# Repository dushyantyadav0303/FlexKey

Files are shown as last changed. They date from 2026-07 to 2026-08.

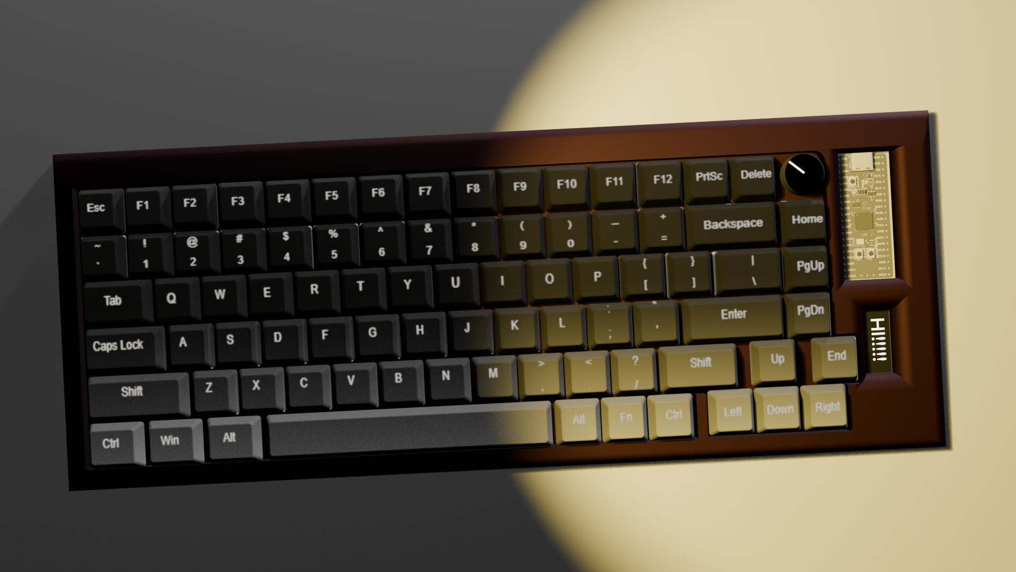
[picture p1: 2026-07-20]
Render/Untitled1.png

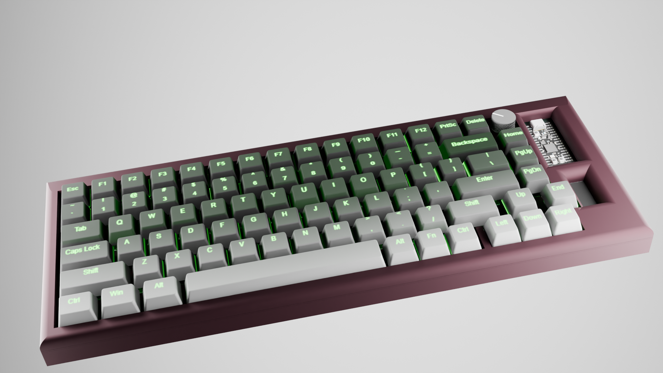
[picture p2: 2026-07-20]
Render/Untitled2.png

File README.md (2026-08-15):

<h1 align="center">
<br> banner
</h1>
<div align="center">  
  

</div>

<h4 align="center">
FlexKey: it is a Fully Customizable OpenSource 75% Mechanical Keyboard with Ai Powered customizable dashboard with allow user to Type a modify the there Keyboard.
</h4>

<div align="center">
  




</div>

<p align="center">
  <a href="#about-the-project">About</a> •
  <a href="#repository-structure">Structure</a> •
  <a href="#schematic">Schematic</a> •
  <a href="#pcb">PCB</a> •
  <a href="#cad">CAD</a> •
  <a href="#Render">Render</a> •
  <a href="#bill-of-materials">BOM</a> •
  <a href="#license">License</a> •
  <a href="#credits">Credits</a>
</p>  

<p
  align="center">
  
</p>

</p>

<br>
<br>
<p align=center>

demo

</p>

> [!IMPORTANT]
> # PLEASE Check [How-to-Build](https://github.com/dushyantyadav0303/FlexKey/blob/main/How-to-Build.md) 
> ### It contain Beginner Friendly Step by Step Assembly Instruction Docs.

### About the Project

**FlexKey:** It is a Fully Customizable OpenSource 75% Mechanical Keyboard with an Ai Powered customizable dashboard with allow user to Type a modify the there Keyboard.

### Features

- **Rpi2040 MCU**
- **Type-C/Micro-USB**
- **KMK Based Firmware**
- **75% keyboard with 84 Keys + Encoder**
- **Modify with Ai Dashboard**
- **Customizable RGB Matrix**

## Repository Structure

- `src/Kicad/` - Kicad PCB sources
- `src/CAD/` -  editable .STEP file 
- `src/CAD/Fusion 360/` - Fusion 360 CAD sources
- `src/Blender/` - Blender Render sources 
- `production/PCB/` - PCB fabrication files (Gerbers, BOM, positions)
- `production/CAD/` - 3D-printable files (.3mf/.stl)
- `GETTING_STARTED/` - Setup guides
- `Journal/` - DevLogs With Timestamp
- `Firmware/` - Base Firmare

## Schematic


Source : `src/Cad/.Sch`


## PCB 
Source : `src/Kicad/.Pcb`
<div align="center">

| Front PCB | Back PCB |
|---|---|
|  |  |
|  |  |

</div>

### Fabrication Production files are available in:
- source: `production/PCB/`

## CAD


- source: `src/Fusion 360/`
<div align="center">
<table>
<tr>
<td valign="bottom">
</td>
<td valign="bottom">
  </td>
<td valign="bottom">
</table>
</div>

> [!TIP]
> Wait for bed Plate to be cool down before Taking out prints. <br/>
> To prevent from warping and print bending issue.

### 3D-printable Production files are available in:
- source: `production/PCB/`

## Render 


<div align="center">
<table>
  
https://github.com/user-attachments/assets/db8a1d57-0f98-42ea-bc92-7f4cc1325804

</table>
</div>

## Bill of Materials

Source: `BOM/BOM.csv`

| Part name | Quantity | Designator | Footprint | Price (In INR) | Link to buy |
| --- | --- | --- | --- | --- | --- |
| RaspberryPi_Pico | 1 | A1 | RaspberryPi_Pico | 384 | [Buy](https://robu.in/product/raspberry-pi-pico) |
| 1N4148 | 84 | D1-D84 | D_SOD-123 | 1.54 | [Buy](https://robu.in/product/1n4148-1w-zener-diode-pack-of-50) |
| sk6812 mini-e | 83 | DL1-DL83 | SK6812MINI-E | 8.5 | [Buy](https://www.lcsc.com/product-detail/Light-Emitting-Diodes-LED_OPSCO-Optoelectronics-SK6812MINI-E_C5149201.html) |
| RotaryEncoder | 1 | EN1 | RotaryEncoder_EC11E-Switch_Vertical | 42 | [Buy](https://www.flyrobo.in/ec11-rotary-encoder-half-shaft-handle-potentiometer-15mm) |
| oled Disply | 1 | J1 | OLED_0.91_128x32 | 212 | [Buy](https://robu.in/product/blue-oled-display-module/) |
| Key Switches | 84 | SW1-SW84 | MX100H | 7.3 | [Buy](https://www.thecosmicbyte.com/product-category/keyboard-mechanical-switches/) |
| Keycaps | 2 | SW1-SW84 | MX200H | 999 | [Buy](https://amzn.in/d/0iVP38it) |
| Kailh Hot-Swap Sockets | 84 | SW1-SW84 | Kailh Hot-Swap Sockets (CPG151101S11) | 11.6 | [Buy](https://www.amazon.in/HEAVENGLOW-Socket-Connector-Keyboard-Switches/dp/B0H74X3QF5) |
| Stabilizers | 8 |  |  | 32 | [Buy](https://neomacro.in/products/cherry-pcb-mount-stabilizers-clip-in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) |
| Full Case | 1 |  | inc. bottom, Top & plate |  | 3D PRINTED |
| PCB  | 1 |  |  | 2,339 | [Buy](https://jlcpcb.com) |
| M3 heat Insert | 4 |  |  | 3.6 | [Buy](https://robu.in/product/m3-x-6-mm-brass-heat-set-knurl-threaded-round-insert-nut-25-pcs/) |
| M3 Screw H-20mm | 4 |  |  | 2.6 | [Buy](https://onlyscrews.in/products/m3-x-20mm-hex-allen-socket-head-high-tensile12-9-black-anodized-screw) |

> [!NOTE]
> Price As of August 15, 2026 
> & It not Include the Shipping fee <br/>

## License

Licensed under MIT - you can use this commercially, modify, distribute and  Flex key more 
with proper attribution. See [LICENSE](LICENSE) file.

## Contributing

Contributions, improvements, and remixes are welcome! Please read the [CONTRIBUTING.md](CONTRIBUTING.md) guide to get started.

## Credits
<div align="center">
  



 
</div>

This project was created during a [Hack Club](https://hackclub.com) event [Macondo](https://macondo.hackclub.com).
- **[Kicad](https://Kicad.org)** - PCB design and schematic capture
- **[Fusion 360](https://www.autodesk.com/products/fusion-360)** - Cad Designing
- **[Blender](https://www.blender.org)** - Render
- **[KMK firmware](https://github.com/KMKfw/kmk_firmware)**
- **[@NotARoomba](https://github.com/notaroomba) & [@Gabouin](https://github.com/Gabouin)** - Readme template

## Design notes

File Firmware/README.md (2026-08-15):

# Upload the Base Firmware in Keyboard

## Install CircuitPython in Flexkey

- Connect flexkey with your computer. press and hold boot button for 5 second
- A drive named `RPI-RP2` will appear on your computer.
- Download the CircuitPython for Raspberry Pi Pico from [circuitpython.org](https://circuitpython.org/board/raspberry_pi_pico/).
- drag and drop that file in drive `RPI-RP2`.
- Verify it: Check that the drive name become `CircuitPython` from `RPI-RP2`.

## Add kmk_firmware library
- Download the kmk_firmware library from [Repo](https://github.com/KMKfw/kmk_firmware/tree/main/kmk)
- Drag and Drop kmk folder in drive `CircuitPython/lib`

## Add firmware
- open [Firmware directory](https://github.com/dushyantyadav0303/FlexKey/tree/main/Firmware)
- copy all 3 file (code.py, boot.py, config.py)
- Paste in root of drive `CircuitPython`
- And here you go, Your firmware is successfully flashed and you can use the Flexkey

###  PLEASE Check [How-to-Build](https://github.com/dushyantyadav0303/FlexKey/blob/main/How-to-Build.md) for Detailed guide

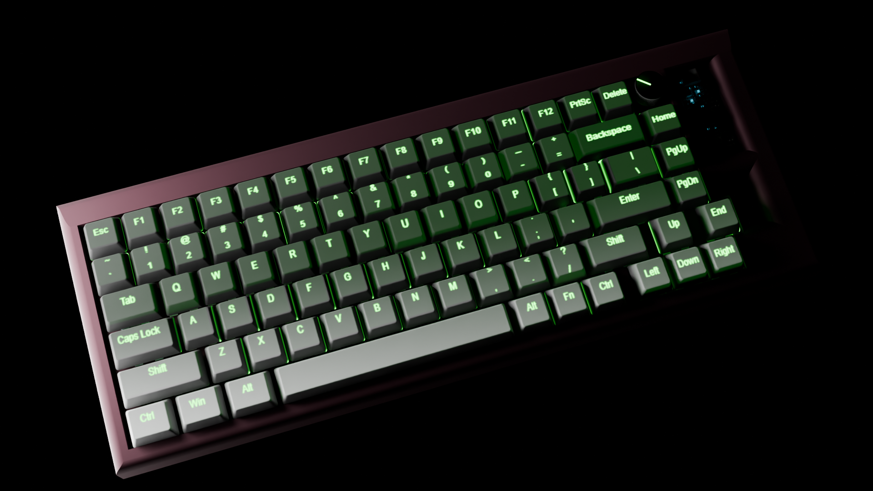
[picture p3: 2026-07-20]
Render/Untitled3.png

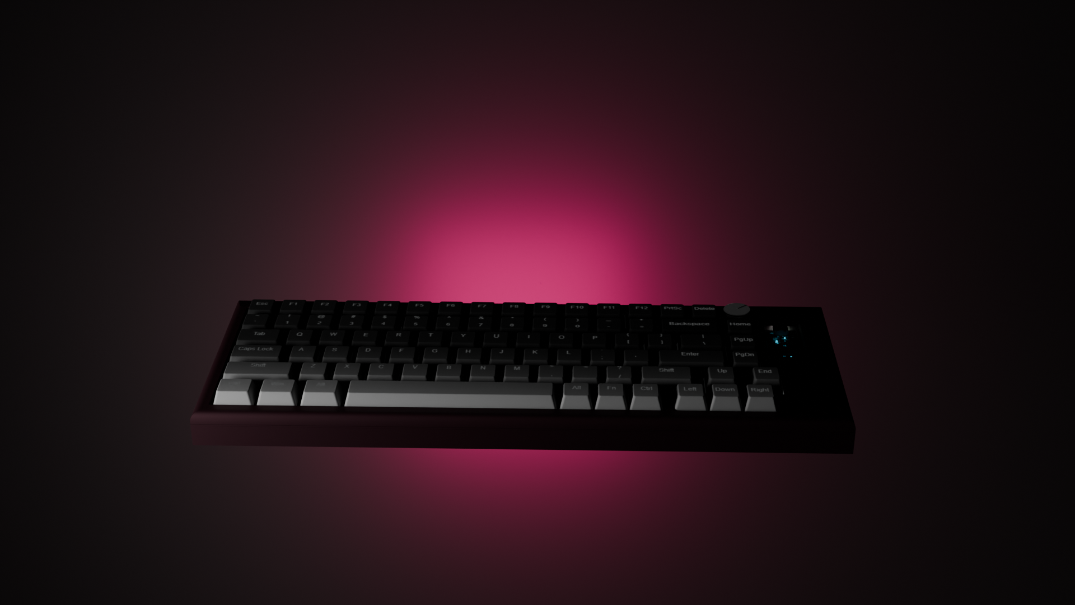
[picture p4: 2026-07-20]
Render/Untitled4.png

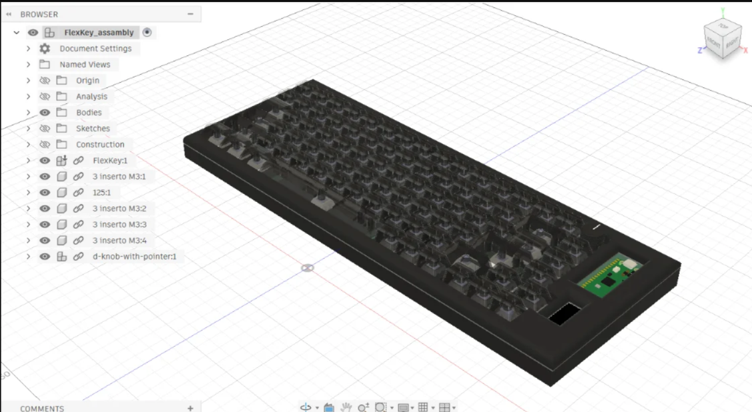
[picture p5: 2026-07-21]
src/CAD/Image.png

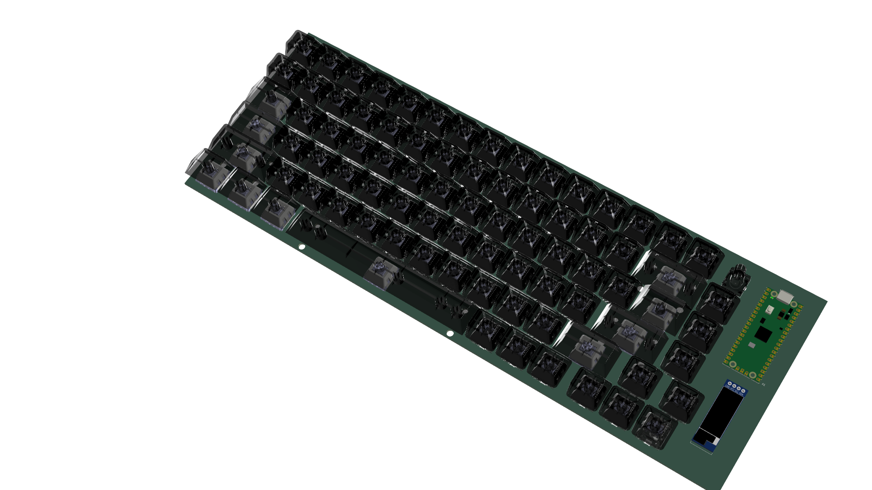
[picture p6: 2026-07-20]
src/Kicad/FlexKey.png

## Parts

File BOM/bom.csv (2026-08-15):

Part name | Quantity | Designator | Footprint | Price (In INR) | Link to buy
RaspberryPi_Pico | 1 | A1 | RaspberryPi_Pico | 384 | https://robu.in/product/raspberry-pi-pico
1N4148 | 84 | D1-D84 | D_SOD-123 | 1.54 | https://robu.in/product/1n4148-1w-zener-diode-pack-of-50
sk6812 mini-e | 83 | DL1-DL83 | SK6812MINI-E | 8.5 | https://www.lcsc.com/product-detail/Light-Emitting-Diodes-LED_OPSCO-Optoelectronics-SK6812MINI-E_C5149201.html
RotaryEncoder | 1 | EN1 | RotaryEncoder_EC11E-Switch_Vertical | 42 | https://www.flyrobo.in/ec11-rotary-encoder-half-shaft-handle-potentiometer-15mm
oled Disply | 1 | J1 | OLED_0.91_128x32 | 212 | https://robu.in/product/blue-oled-display-module/
Key Switches | 84 | SW1-SW84 | MX100H | 7.3 | https://www.thecosmicbyte.com/product-category/keyboard-mechanical-switches/
Keycaps | 2 | SW1-SW84 | MX200H | 999 | https://amzn.in/d/0iVP38it
Kailh Hot-Swap Sockets | 84 | SW1-SW84 | Kailh Hot-Swap Sockets (CPG151101S11) | 11.6 | https://www.amazon.in/HEAVENGLOW-Socket-Connector-Keyboard-Switches/dp/B0H74X3QF5
Stabilizers | 8 |  |  | 32 | https://neomacro.in/products/cherry-pcb-mount-stabilizers-clip-in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
Full Case | 1 |  | inc. bottom, Top & plate |  | 3D PRINTED
PCB | 1 |  |  | 2339 | https://jlcpcb.com
M3 heat Insert | 4 |  |  | 3.6 | https://robu.in/product/m3-x-6-mm-brass-heat-set-knurl-threaded-round-insert-nut-25-pcs/
M3 Screw H-20mm | 4 |  |  | 2.6 | https://onlyscrews.in/products/m3-x-20mm-hex-allen-socket-head-high-tensile12-9-black-anodized-screw

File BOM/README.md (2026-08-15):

> [!NOTE]
> Price As of August 15, 2026 
> & It not Include the Shipping fee <br/>

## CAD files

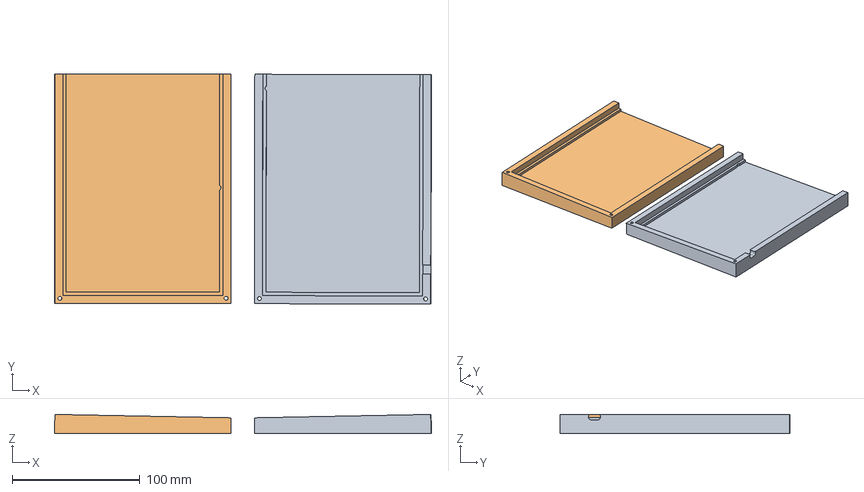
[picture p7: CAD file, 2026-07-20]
production/CAD/3mf file/bottom.3mf
294.9 x 180.0 x 15.0 mm
Bottom (1)
Bottom

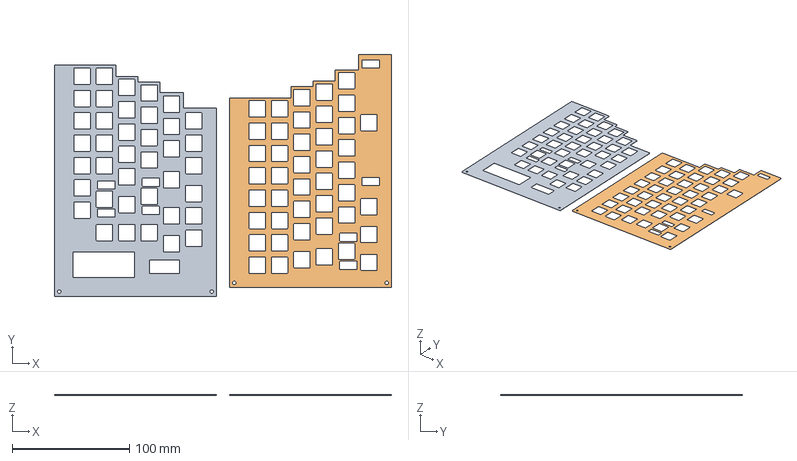
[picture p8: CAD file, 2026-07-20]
production/CAD/3mf file/plate.3mf
287.2 x 205.9 x 1.00 mm
Plate
Plate (1)

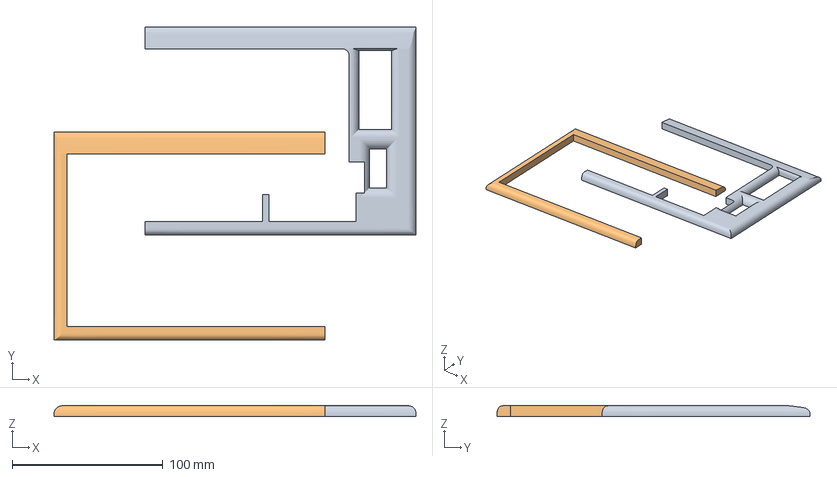
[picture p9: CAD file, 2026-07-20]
production/CAD/3mf file/TOP.3mf
239.8 x 207.6 x 7.00 mm
TOP (1)
TOP

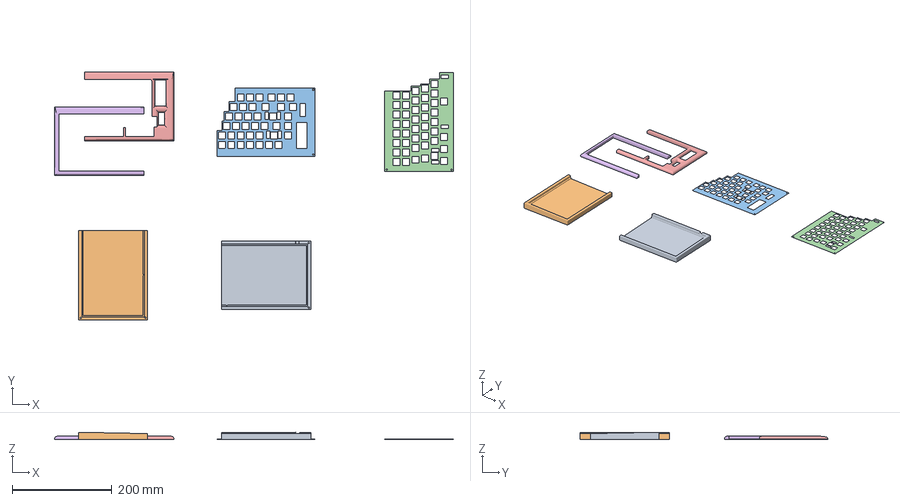
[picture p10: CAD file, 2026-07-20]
production/CAD/3mf file/Combin.3mf
800.9 x 497.5 x 15.0 mm
Bottom (1)
Bottom
Plate
Plate (1)
TOP (1)
TOP

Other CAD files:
production/CAD/stl file/Combin.stl
production/CAD/stl file/TOP.stl
production/CAD/stl file/bottom.stl
production/CAD/stl file/plate.stl
src/Blender/flexkey.blend

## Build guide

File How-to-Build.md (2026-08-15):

# Welcome Hackers!
## I glad to see you here that you like this project and want to Build it once for your Self
# Table of Contents

* [Fabrication](#Fabrication)

  * [PCB](#PCB)
  * [Case](#Case)
* [Assembly](#Order-Components)
 
  * [Soldering](#Soldering)
  * [Step 1](#Step-1)
  * [Step 2](#Step-2)
  * [Step 3](#Step-3)
  * [Step 4](#Step-4)
  * [Step 5](#Step-5)

## Fabrication
#### For Fabrication You can either Do it yourself or outsource it

### PCB
Source `production/PCB/Flexkey_GERBER`
- Download the Gerber file
#### For PCB Fabrication if you have All the equipment for PCB fabrication. Congrats Fabrication it your self.
#### else
#### Fabricate it through Any PCB Fabricating companies LIKE:
- [JLCPCB ](https://jlcpcb.com)
- [RobuPcb](https://robu.in/product/online-pcb-manufacturing-service/)
- [PCB way](https://www.pcbway.com)
- [lioncircuits](https://www.lioncircuits.com)

### Case
Source `production/CAD/`
For fabricating case you can use CNC Machine & FDM or Rasin 3D printer
#### **Recommended:** GO with Aluminium case it gives really Premium I'm stable Typing experience
If you dont have such equipment don't worry go with Some 3d Printing companies like:
- [JLCCNC](https://jlccnc.com)
- [JLC3DP](https://jlc3dp.com)
- [Robu3DP](https://robu.in/product/3d-printing-service1/)

> [!TIP]
> If you are Self 3d Printing with FDM printer. <br/>
> Wait for bed Plate to be cool down before Taking out prints. <br/>
> To prevent from warping and print bending issue.

## Order-Components
Source `production/BOM/`
### After all of this order mention in BOM
### Things that you can customise it Without modifying the Production file
- keycaps grafic
- Switchs
- Encoder Nob
### If you want to modify the files 
#### then it opens Infinite possibility for you

## Assembly 
### Soldering
- Either you can hand solder it
or 
- select PCBA while ordering PCB

### Step-1
#### Insert the heatinsert inside the Case
- First, Take a M3 Heatinsert 
- Aline on hole in top Part of case
- Put the heated Soldering iron to top of the Heatinseart with a Gentle presure 
- once it's inside take up the soldering Iron

### Step-2
- Put the Base Part of the case
- place the pcb on it  
- place the Plate on top it
- Place TOP Part of the Case on top 
- Screw in all 4 screw 

### Step-3 
### Upload the Base Firmware in Keyboard

#### Install CircuitPython in Flexkey

- Connect flexkey with your computer. press and hold boot button for 5 second
- A drive named `RPI-RP2` will appear on your computer.
- Download the CircuitPython for Raspberry Pi Pico from [circuitpython.org](https://circuitpython.org/board/raspberry_pi_pico/).
- drag and drop that file in drive `RPI-RP2`.
- Verify it: Check that the drive name become `CircuitPython` from `RPI-RP2`.

#### Add kmk_firmware library
- Download the kmk_firmware library from [Repo](https://github.com/KMKfw/kmk_firmware/tree/main/kmk)
- Drag and Drop kmk folder in drive `CircuitPython/lib`

#### Add firmware
- open [Firmware directory](https://github.com/dushyantyadav0303/FlexKey/tree/main/Firmware)
- copy all 3 file (code.py, boot.py, config.py)
- Paste in root of drive `CircuitPython`
- And here you go, Your firmware is successfully flashed and you can use the Flexkey

### Step-4
#### Modify it using Ai

https://github.com/user-attachments/assets/dde2330e-e5ff-4832-9f8f-4e7bbd5d7b11

- Go to FlexKey Webapp https://flex-key.vercel.app/home.html
- open Modification Workspace
- press and hold boot button untill it goes in boot mode
- Connect with Webapp with a connect button on top right corner
- Ask Ai to modify your flexkey 
- click flash key 

### Step-5
#### Test the Keyboard



- you can test the Keyboard in webapp inself 
- press any key it will show up in dashboard only
- also the RGB animation you selected , Display text , Muchmore

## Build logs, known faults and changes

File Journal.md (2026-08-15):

# FlexKey Project Journal

A complete log of the FlexKey development journey on Macondo Platform.

## 2026-08-13 | 14:48 | Troubleshooting + Complete build
**Hours Logged:** 1.5
 
hemlo gng,
Today I'm Assembling all the things. And complete the build !!!
It looks so nice After Assembling it <br/>
 <br/>
Then I troubleshoot the firmware in [thonny](https://thonny.org) Where I found some issues of Key misconfiguration and lib related issue Which I fix it and push it to github. <br/>
 <br/>
 
---
 
## 2026-08-13 | 06:35 | Keys...!
**Hours Logged:** 2.3
 
Hello gng, How was your day going? <br/>
I order all type of Switch available on [cosmicbyte](www.thecosmicbyte.com). <br/>
& today I Receive all the keyboard Switches. <br/>
which looks sick fr <br/>
 <br/>
Next i 3d printed the Keycaps <br/>
And I figure out the easiest way to take them out from Bed. <br/>
just drop the build plate on floor And all the keycaps will take out in once (Please don't try cause It damage your build plate, I did this by mistake.) <br/>
 <br/>
it having a tight tolerance So I have to heat this up a bit using Hair dryer. <br/>

**caution** : over heat or too much force will deform it's shape. <br/>
 <br/>
Proof of time: It take a lot of time to Heat a single key and Fit it. <br/>
  
---
 
## 2026-08-11 | 20:13 | 3d print Case
**Hours Logged:** 0.2 
helo! <br/>
today, I 3d print Case for Flexkey. <br/>
~ Source [production/CAD/](https://github.com/dushyantyadav0303/FlexKey/tree/main/production) <br/>
also to join them properly I use little bit Super Glue. Cause due to Build volume I split 1 object into 2 part. <br/>
 <br/>
 <br/>
 
---
 
## 2026-08-11 | 20:02 | Important Update !!!
**Hours Logged:** 0
 
I'm Start building my project! <br/>
I complete my design on 21 july and ship it for design review. <br/>
but after 22 day I withdraw my project from design review. Since this is self funded project i already order all the Items. all of them are delivered. <br/>
Now, I start building the Flexkey in irl. <br/>

 
---

---

## 2026-07-20 | 04:06 | Finally added
**Hours Logged:** 1.3

Finally I added!!!!
After lot Research + Learning all Abt Git (btw it The tutorial I watch of 2hr)

So what i did first i use git bash method {Failed}
Second i use github Destop app Surprisingly it work but only for Render file cause it 10 file in folder ~8mb each but it not upload the .blender file which is ~100mb 
Then i use github lfs with Git bash then it works!!!! so it created a .gitattributes file which have so data that link it to there big data base smth I am not sure at all {i not devloper of github}



---

## 2026-07-19 | 03:51 | Upload files to Github
**Hours Logged:** 0.9

Today, I upload all the file to github it,
So i export all the SRC and Production files to different software like kicad, Fusion360, etc!!! also exporting .step file kills my pc. my pc got crash 2 time in between but some my homework are not save which get lost!!!! AHHHH!!

Add then i upload on github but .blender and few more file are bigger file then the leave it for now since i all Frustrated.



---

## 2026-07-16 | 22:52 | Readme #2
**Hours Logged:** 0.7

So today, i start with readme only 
First i add the Repo Structure which might be edit in future if required.
Next i add the Pcb Systematic details
Here you see



Then i added some Pcb Board deatils



---

## 2026-07-15 | 23:41 | Readme #1
**Hours Logged:** 1.2

Nǐ hǎo ^_~

Now i start with Readme part.
So First I added the most Attractive part of the readme: Badges, Logo, Render, TOC & more



Also it take a Hella of time just to upload the the video cause the main video in high resoulution which make the video Size high and i also not want to change the resolution but I'm not a devloper of github i have to Compress the video at the end.

Next i add the some basic detail about it



---

## 2026-07-14 | 18:19 | How-to-build #3
**Hours Logged:** 1

Olá!

Today i am add more in How-to-build.md
I added the how to flash Firmware + how to modify it using flexkey Webapp 
With the demo video!



---

## 2026-07-13 | 22:56 | How-to-build #3
**Hours Logged:** 0.8

Olá!

Today i am add more in How-to-build.md
I added the how to flash Firmware + how to modify it using flexkey Webapp 
With the demo video!



---

## 2026-07-12 | 22:17 | How-to-build #2
**Hours Logged:** 1

Ciao!

Today i more on How-to-build.md 
I start with what to order, how to order as per there tech Skill
Plus how to solder
Also 3 step to building it in IRL




---

## 2026-07-12 | 06:03 | How-to-build #1
**Hours Logged:** 0.8

JAJAJA gng! {new way of greeting}

Today i am starting a new file How-to-build.md in which 
I'm make a complete guild to build the Keyboard in IRL

So i start with very far beginning:
- How to Fabricate PCB and Case + source + etc.



---

## 2026-07-10 | 09:41 | Cad Production File
**Hours Logged:** 0.6

Hello, today I prepare the Case Production file

Most of the Clubber have 256^3mm volume Printer so Printing the whole Model is not possible 
So I split them in 2 Part for each body. in that manner it not break while Printing and using it,

After all here is preview



---

## 2026-07-10 | 04:45 | Webapp #3
**Hours Logged:** 3.7

yooooo! guys,

Finally I built this "Modify with AI feature" it is Insane feature Just type and get Customized. 
How crazy it was!
Like just see the Code 

Ik I use AI to make the work little bit easier. But Still it takes a hella of time



I ensure every Config file it flash should be Correct and not broken.
Also you don't need to download the file and upload it, It do all of this for you.
It is very good for beginners.

Here is demo

video

---

## 2026-07-09 | 03:44 | Keys Tester
**Hours Logged:** 1.2

Today, I build the KeyTester as a part of Ai Modifier.
I replicate the same layout of my keyboard and the keys. It helped to test the keyboard
Whether everything is connected fine or not.

**Tip:** If some key are not detected check:
- Does the Keys are properly connected with hot Swap connector 
- Does the Every component is soldered properly
- Change the Switch 

Here it's demo



---

## 2026-07-08 | 19:40 | Firmware
**Hours Logged:** 1.7

Hola gng! 

Today I Building the firmware for flex key

First I started by Researching about firmware available:
- KMK
- QMK

KMK is CircuitPython based Firmware
QMK is C++ based Fireware

I'm going with KMK Firmware cause it's easy for Ai to configure and change Parameter.
So, After some research I built this firmware "It looked little bit like AI cause I made like that Only Cause it is manage with Flex-bot.

Here is the Firmware 



---

## 2026-07-07 | 20:32 | Webapp #2
**Hours Logged:** 1.9

Today, I working on the webapp day 2 

SO I build the Home page of FLexKey. 
Which Include Keyboard Detail, Highlight and features and redirect button to our "Modify it Using AI" button. Again i Talk abt it later,

Here is the final look!

video

---

## 2026-07-05 | 05:50 | Webapp
**Hours Logged:** 1.1

Helo guys!,

Today, i start building webapp 
Where I Description and detail about the FlexKey and main Thing is that Ai power Customizable Deskboard. I will talk about it more later,

So today I'm planing to start with landing page.
So here is the today progress

video

---

## 2026-06-30 | 18:29 | Final Animation!
**Hours Logged:** 0.7

Ah-LOH (～￣▽￣)～

Finally I completed it.
So today i Finally complete the editing With Some fixes

Here is the Capcut timeline



Wait is finally completed! 
Here is my masterpiece 

video

---

## 2026-06-29 | 18:17 | LOGO!
**Hours Logged:** 1.3

Hey yah!

Today I am Making the logo or Static render of Flexkey.
SO I plan to Make a render in which the flexkey keyboard is really show there Flexibility means I am Twisting this keyboard.

So while I'm doing this it Take a lot of time One and only reason Splited keyboard part. ahh I get frustrated with this split body. Anyway if I commit I will do it.

Finally finally finally it is completed!

Setup



Logo



> Hint: Final video is cooking in background.

---

## 2026-06-28 | 22:55 | Scene ∞
**Hours Logged:** 0.8

Hello!!

I get Tired ahh!!! making this Scene.
Today, We are making Scene ∞, lol maybe it's the last scene left.
SO i make a Key popout Scene in which nothing Great happen just the key pop out.

Here U see

video

> Wait Don't worry how this key goes back to place. I will play the scene in reverse.

---

## 2026-06-27 | 18:27 | Fix! Gradient effect
**Hours Logged:** 0.7

HELLO!, 

Today I am gathering all the Clips for Final render but I saw that the Gradient texture look corrupted in scene 5 Cause I Separate all the keys For typing animation. Due to gradient effect is split for each key. 

Which looks like this 



So I Again I have to fix it up Ahhh!!! My pc cry every time when i say "Render it"

Here is the Fixed! video 

video

---

## 2026-06-26 | 18:30 | Scene #5B
**Hours Logged:** 1.3

Today, I make the part B of scene 5 
Cause I am not 100% Satisfy with the yesterday Animation So I Made a New one. In which I changes the RGB led. Previously there is only a still light But Now I added 7 colour rgb animation. which really gives Gaming Vibe.

Here is the Animation

video

> Also i use the Previous Animation in Final render

---

## 2026-06-25 | 18:27 | Scene #5
**Hours Logged:** 1.8

hohoho! Today I'm make Scene 5 

In Scene 5 what i plan is that:
- First the Typing Animation started. which is Gradually Increasing
- In display High WPM sign glow with Red flexkey RGB
- the Key get pop out 

That is my plan. It's time to execute it

For typing Animation I use a Python script feature in blender. After all this work.

Here is the Final Animation

video

---

## 2026-06-24 | 17:34 | Scene 4
**Hours Logged:** 1.6

HIII! , Today I making Scene 4 

Yesterday, I make a animation of connecting the power Cable Now today i Make the Boot Up Animation 

Let's goo!

What i plan: First all the Lighting Get Flickering Start means the Light get blink few times before starting.
Second the display starting animation, The animated video play in Display to show the Boot UI Animation,

Today is the final animation!!

video

---

## 2026-06-22 | 20:46 | Scene #3
**Hours Logged:** 2.8

yooooo gng!, \\^o^/

Today, i'm making scene 3 of flex Key animation.
In which I'm showing the Cable going From Pc and connecting to Flexkey. 
It is not easy at all!!!! it take a Hella of time & experience which I got while building Macondo projects only "thank you HC!!!!"

Here is the result "Very Crazy!!!!"

video

> By the way don't get confuse from were the wire get spawn. It just behind the monitor I use the path feature + hella of thing to made it 

video

---

## 2026-06-21 | 17:38 | Scene #2
**Hours Logged:** 1.2

Hola!, Today I complete Scene 2 if it not dance today,

Yesterday I use Physics Property To replicate the gravity but There is some issue model.
Today i use Keyframe to Manually gave Falling effect look. in which I Manually Adjust the rotation and the location in timeline. Also after it i Adjusted lighting for desk and Fade top light so it not Interrupt Desk lighting. 

Here you see how it look now!

video

---

## 2026-06-20 | 17:17 | Scene #2
**Hours Logged:** 1.5

Hii! gng Today I am making Scene 2 

In scene 2 the keyboard is falling down to Desk 
For that I'm using Physical property feature of blender, Where we can replicate the Physics and gravity laws. but there is issue with Flexkey it is split into Multiple parts/Body due to that It is very difficult to Join them together while falling And Rn it scatter in air. 

See WHY THEY ARE DANCING (T_T)



Also I change a lot of settings but it still Behaving the same as before 

**Conclusion:** I get frustrated and leave it. now i see it Tomorrow.

---

## 2026-06-19 | 18:26 | Animation Scene #1
**Hours Logged:** 0.9

Helo! ^_^ today I Animating the Flexkey Scene 1

Yesterday, I completed the lighting part now I Animate it. It looks soo goood as i Expect but It take a lot of time to render due to my Laptop with Rtx 2050 which is not Enough. I need to upgrade Ahhh!!!

Any way enjoy!!! ↓↓↓↓↓↓

video

---

## 2026-06-19 | 05:45 | Add lighting
**Hours Logged:** 1.2

Yooo! Today I Add Lighting for Render Scene 1

Lighting is one of the main thing in Blender. So I spend a lot of time on Researching about lighting and related stuff. {It's looks soon I'll become Light Engineer with Youtube Certification JSAJSAJSAJSAJS}

Yea lighting a divide in 2 parts:
- Background light 
- Product light

In my previous project I don't spend time on lighting but now I know the Difference.

Here is You see Lighting 



Here is the setup



---

## 2026-06-17 | 18:12 | Render SnapShot
**Hours Logged:** 1.4

HI! gng

Today I'm making some Static render of flexKey,
So before making animation I click some Render of Flexkey. also i can control the RGB leds of keyboard which make it more Cool. 

Here you Goooo!




---

## 2026-06-16 | 18:59 | Adding Characters on keycaps
**Hours Logged:** 1.9

Hi!, Today I see that something is Missing on the keyboard Which is none other than the Characters.
Lol how i forgot about it, So I I have two options to add the Characters:
- Manually with the use of text box (ahh Unprofessional)
- Using UV Projection (Professional)

I think you all know I am going with the UV projection only. First i make the Image with Characters. for that I use [keyboard-layout-editor](https://www.keyboard-layout-editor.com) and export it into PNG 

After 5 fail trial i finally made it 



Then the most time taking process ahhhhhhh! Align the keycap on top of Image. Really ton of time.
After that i added Nodes to show both gradient effect and text effect with RGB Lighting

Here you see the final look:

 

Here how Adjust RGB lighting 



---

## 2026-06-15 | 17:47 | Change RPI pico
**Hours Logged:** 1.8

Helo gng!, today I saw that one thing that ruin the whole Beauty of the flexKey.
Which is none other than Generic Raspberry Pi Pico 3d model 
Which look like this In between of our flex key



For solution I remember that I saw one hack club official Raspberry Pi Pico But I don't know where it is exactly. After exploring I found it into #beest shop



Which look very beautiful in Comparison to our Raspberry Pi Pico also i love the SilkScreen 

Now the next problem begin Where I found it 3D model?!!!!!!!
For the solution I start exploring Then finally finally finally I found the repo But there is no 3d model file. Can I start finding the detail about the creator. but afaik he leaves Hack club. 

Then I'm feeling hopeless. But suddenly I saw Kicad Source file. Which I import in my kicad →

 

But there are some missing Component in it. So I find it on Internet And added it 

NOW! Finally I have 3D model of Orpheus Pico




The export file in .step that I Import in my fusion 360 and Export it in .obj
Which I finally Upload in my Flexkey

After Some Align It look like this:



> Sorry bad lighting

---

## 2026-06-14 | 18:26 | Add texture
**Hours Logged:** 1.9

Hola OwO!, today I added texture in Encoder Nob + Switch of FlexKey,

**For Encoder Nob:**
- I add Keys matching texture 
- Glowing pointer



**For Switch:**
- Transparent casing which allow to see inside mechanism.
- Red socket which look Totally separate from the keyboard Which is good while making animation.
- Mechanical mechanism is gold and copper



---

## 2026-06-13 | 18:23 | Add Texture on Keycap
**Hours Logged:** 4.6

Ah-LOH!(～￣▽￣)～

Today, I'm adding texture on keycaps. 
I have to add 2 effect:
- Rough/Matte texture on keycaps 
- Gradient Effect "hard"

So first I added the matte texture which is not so Difficult or complex it just take time.

Here you see the matte texture 



> It might be Difficult to see because of the bad lighting but Definitely you will see in render.

Next i added the gradient texture which make me cry while doing it. cause it very Difficult too Manage the orientation and intensity Graph,

Still I complete it just see the Node it 





It look damn crazy which which Totally worth it for time.

---

## 2026-06-12 | 18:24 | Add Case Texture
**Hours Logged:** 3.7

Vanakkam!, Today I'm adding Texture on Bottom + Plate + Top Part of the Flexkey.

I'm very Excited cause i'm first time adding adding texture in blender, Previously I added the texture in Fusion 360 but it's kinda drag and Drop like a Kids Drawing but now I'm Finally moving on real engineer tool AJAJAJAJA!!!!, 

It is very confusing BUT Very interesting I kinda enjoy learning this. I don't know when it takes 3.7 hr Doing this. 

Are you excited to see it!!! AJA
I am not Training a model AJSAJSJAJA.



> I Recommend you to turn on **Node Wrangler** Add on before staring

---

## 2026-06-11 | 18:22 | Arrange Keycaps
**Hours Logged:** 1.7

Ah-LOH!, Today I'm Arrange all the KeyCaps on the Flexkey.

It take lot of time to arrage all the Keycaps. I use modifier Called "Array modifier" which help arrage object in equal distance which save my lot of time but still take alot of time there is key of Different sizes and All the keys not in Uniform gap. In total there is 84 keys

Here you See !!!




---

## 2026-06-10 | 17:12 | Custom Keycaps
**Hours Logged:** 0.8

Hey!, Today I Design the New keycap For Flexkey in **Blender**

Previously I added OpenSource Public keycap Which Is not consistent Means Different Keycap have different height and tilt which Looks bad and not good for Render.

For solution I design new keycaps in blender But I only make renders and animation Before in Blender I never designed any 3d model before. So i have to learn it but I prefer to learn by our self by hit & trial Not just open Tutorial and watch it.

I completed my Keycap but There is a Issue I have to design new keycap For different sizes which take a lot of time But I find solution On Internet. In which We are cutting the Keycap from middle After We can just extend it as much we want.

Here is you see 

**In edit mode:**



**In Object Mode:**



---

## 2026-06-09 | 18:27 | CAD #3 + Final Touch
**Hours Logged:** 1.4

Ni hao! Today I'm Completing the case TOP Part With Final polishing.

There is nothing great for the top part, It just take time to Precisely Align it So the Keys not get Visible and stuck and I make the Smoother slide surface as Good Ux 

Here you see



**Key changes I made:**
- I added a Cool Knob for Encoder 



- Added Brass inserts and M3 screws



---

## 2026-06-08 | 17:27 | CAD #2
**Hours Logged:** 1.2

Today, I moving forward to Case Bottom part

First I'm Curious how Fix this PCB on case But after a lot of research I figure out that The PCB is not at all Connected with the case There is just a layer of soft form Which reduce on Vibration, While building the case the most of the time is taken For a research part only. also On Internet There is not Much information available For making it from scratch.

After all of this see how I manage it




**Proof of time:** The main time is taken In Research part and Aligning them and Managing the tolerance & UX.

---

## 2026-06-07 | 18:27 | CAD #1
**Hours Logged:** 1.4

Today, I Started with making Case of the Keyboard

Keyboard I divided into Multiple layer:



In which I completed:
- PCB
- Switch
- Keycaps

Now, two things are left Case and plate. 
First, I made the Plate, While Researching I found a tool which Convert our Keyboard layout. Json to SVG Which we can directly import in our fusion 360 and excrude it. the Tool is [ai03 Plate Generator](https://kbplate.ai03.com) 

But wait it only give you switch cutout remain you have to do your own 

Here is My Flexkey Plate




---

## 2026-06-06 | 18:23 | Added 3D Model in PCB #2
**Hours Logged:** 2.6

Today, I added all the remaining 3D Model 

But it Sound Simpler but I have to create new Cad model for Every different KeyCap Also i have to add encoder & Display 3D Model, so it's Simple but Take Time.

**Final PCB:**



**In exported Fusion 360:**



---

## 2026-06-05 | 18:12 | Added 3D Model in PCB
**Hours Logged:** 1.4

Today, I Added the Keyboard switches 3D model 

But there's a issue We can only 1 CAD Model in Kicked for 1 Footprint So whether I can add Switch or Keycap or that Hotswap connector.

For Solution i Downloaded All these three CAD Model from Internet and Import In Fusion 360 & Align them properly So I get a single Cad File Which I uploaded in my kicad

**Here How the Final model looks like:**



**Here How the PCB look like:**




> Rn I only Uploaded the Mx100H footprint

---

## 2026-06-04 | 18:27 | Added silkscreen
**Hours Logged:** 0.9

Today, I Added silkscreen On my PCB 

First I am very confused what I had in my PCB But after thinking a lot With a blank Mind I added Macondo Logo.

**3D View:**



---

## 2026-06-03 | 17:07 | Assign footprint + Cosmetic changes
**Hours Logged:** 1.2

In the keyboard the different keys have different sizes So I assign all the respected footprint according to their key size. 



Also I made Some Cosmetic change by Relocating the comments And User mark 



---

## 2026-06-02 | 13:09 | Complete Routing
**Hours Logged:** 1.9

Yesterday my half of my routing is completed, Now today I am moving on to The remaining half routing I started with 

**Routing the LED matrix** It is little bit interfering with Row and column Route but I manage it By using Via.

Then I Route the remaining over component so EX. Display Add encoder.

**After all here's my PCB:**




---

## 2026-06-01 | 17:25 | Re-Route PCB
**Hours Logged:** 2.4

Finally all the Row and Col Arrange properly I start routing it up 
Then I layout the PCB This time it is no SO diffcult this time, And I placed the encoder manually
Without the use of plugin

**Route switches:**



---

## 2026-05-31 | 18:21 | Recreate Switch Matrix
**Hours Logged:** 1.2

The whole old matrix It's kind of trash So I decided to recreate it, this time I make it 6 Row x 15 col 
And make the encoder Separate

**Here's the final Switch matrix:**



---

## 2026-05-30 | 17:19 | Fixing Systematic
**Hours Logged:** 1

See we made a constellation not of star but of components



I Made Huge mistake in my systematic leads to The rows and column Are misaligned !!! 
It most probably looks like Switch have wrong sequence issue.

Now back to work on systematic

---

## 2026-05-29 | 18:39 | Route led matrix
**Hours Logged:** 1.2

Today I Route LED Matrix In the keyboard, It is Really very difficult To use kicad cause I'm not use too with it. But still I want to learn!

**Here is Route image:**



Also I change the footprint of A space key.

---

## 2026-05-27 | 23:29 | Layout PCB
**Hours Logged:** 4.1

I already Prepare the Layout in [keyboard-layout-editor](https://www.keyboard-layout-editor.com) So i use KB Placer Plugin to Layout the Keys but I When I put the .Json layout and press enter it gives me thousands of error,

First it takes a lot of time to Figure out what Wrong with it, then I get know that the Diode are Not in a proper Sequence As per row & Col. So the Error goes and the PCB layouts but the pain not ends here



I find out the Diode and Switch are not arrange properly means with Switch 1 --> Diode 4 is Aline Which create a lot of mess Then I understand the previously I make the Key matrix in which the SW{x} Switch Number X is Not proper Sequence As per row & Col which Make a big issue Which I need to fix it.

And all these things and fixing it Takes around **3.2Hr**

**Here is the systematic after fixing it:**



Now everything is in proper Sequence,
Then after running the kb placer plug And Adjusting the parameters then.

**I finally Layout Keyboard:**



---

## 2026-05-27 | 17:39 | Fix ERC & Assign Footprint
**Hours Logged:** 1.8

Before Moving on PCB I Run ERC (Electrical rules check) And there is many Error Which i am Ignored before. then I start Fixing them All the Error and Warning.



**Then I Assign Footprint:**
- For Diode - SOD-123
- For Encoder - E11
- Switch - MXH100

Then is Along Story for Finding Footprint of Switches, Cause I want to make this Keyboard Fully Customizable I want to add Hot Snap Foot print which i unable to Find and once i get on SnapMagic it is Fail to Download I try 100 time to Download but it fail then I find this [Repo](https://github.com/AcheronProject/acheron_MXH.pretty#) For Footprint I really Thanks to [AcheronProject](https://github.com/AcheronProject) For making this Repo.



---

## 2026-05-26 | 12:19 | Layout the Keyboard
**Hours Logged:** 1.8

So the things I Decide before that it is 75% Keyboard with 83 keys and 1 encoder. Now i Move on to 
[keyboard-layout-editor](https://www.keyboard-layout-editor.com) TO design the Keyboard 

**Here is the Layout I design:**



Let's look too simple but there is a feature keyboard-layout-editor To color the keys and text With the use of command Before the key:
- For Text color: `{t:"#0099ff"}`
- For key color: `{c:"#1a1a1a"}`

**NOTE:** `#0099ff & #1a1a1a` Are hex code of color blue & black. Just change it for different colors

Then I color all the keys and text to give it Gaming keyboard vibe

**Here is the final layout:**



---

## 2026-05-25 | 17:09 | Complete Systematic
**Hours Logged:** 1.1

Now I'm Finally Completed the Systematic by adding:
- Rp Pico with RP2040 As a MCU Cause it is Commonly uses for keyboard, It is good for HID & It have enough Pin To manage all this thing.
- 5 PIN rotary encoder - Which can be used to interact with UI And control volume ofc customize as user And Inbuild push button is Used as key 
- Added A Oled Display port Which support all Display uses I²C Protocol

**Here is Final Systematic:**



---

## 2026-05-24 | 07:58 | Working on Systematic
**Hours Logged:** 1.4

Today I plan to Make Led matrix for the Keyboard And of course It is fully Customizable Have Some Preset Animations Inbuild, First I selected the Led. I want a led which is small, less power Consumption ~0.01A per led. I found Sk6812 Mini which is Fit in overall criteria but it takes 0.06A which is very high but we can optimize it by adjusting the Brightness, 

Then I move the Systematic Part and prepare the Led matrix. 

**Here is Result:**



---

## 2026-05-23 | 17:55 | Systematic
**Hours Logged:** 1.2

I decided To make 75% key board which have 81 - 84 keys Usually

My plan to make a it 84 keys in which 10 Column and 9 row for 83 Normal Keys and 1 Button in Encoder Which Should be Customize. ALso i don't wanna add any Separate key for Keyboard UI interface. I use Keyboard keys only with the combinations To interact with Ui. Like make Combination Function + S To enter in the Ui then With the help of display and the encoder To go in more further menu. And after you are out of the ui of Keyboard then the encoder is use for Volume or Customise as per requirement.

After all this Decisions I completed my keys Matrix

**Here you See:**



---

## 2026-05-22 | 18:29 | Feature planing
**Hours Logged:** 1

I know you also like Fully customize Keyboard, It is easy for developer like us But not for non technical and Beginner to make their own keyboard.

For that Our **FlexKeys** Comes in Which is Fully customizable & Open source Keyboard Which allow everyone To customize there:
- Switch
- Lighting
- Display
- Much more

Hot swap Switch Help to Change the Switch without Soldering



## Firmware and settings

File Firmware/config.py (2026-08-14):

# config.py - Generated and Managed by Flex-Bot
# visit: https://flex-key.vercel.app for more info

from kmk.keys import KC

DEBOUNCE_PRESS = 5
DEBOUNCE_RELEASE = 5
OLED_MODE = 'TEXT' 
OLED_TEXT = "FlexKey 75%"
OLED_FLIP = False
# LED_MODE: 0=Off, 1=Solid, 2=Breathing, 3=Rainbow Cycle, 5=Reactive (glow on keypress)
LED_MODE = 1
LED_HUE = 20
LED_SAT = 255
LED_VAL = 150
LED_SPEED = 10
PER_KEY_RGB = {} 
ENCODER_MAP = [ ((KC.VOLD, KC.VOLU),), ((KC.MW_DN, KC.MW_UP),) ] 
MACRO_1 = ""
MACRO_2 = ""
MACRO_3 = ""
MACRO_4 = ""
MACRO_5 = ""

KEYMAP = [
    [
        KC.ESC, KC.F1, KC.F2, KC.F3, KC.F4, KC.F5, KC.F6, KC.F7, KC.F8, KC.F9, KC.F10, KC.F11, KC.F12, KC.PSCR, KC.DEL,
        KC.GRV, KC.N1, KC.N2, KC.N3, KC.N4, KC.N5, KC.N6, KC.N7, KC.N8, KC.N9, KC.N0, KC.MINS, KC.EQL, KC.BSPC, KC.HOME,
        KC.TAB, KC.Q, KC.W, KC.E, KC.R, KC.T, KC.Y, KC.U, KC.I, KC.O, KC.P, KC.LBRC, KC.RBRC, KC.BSLS, KC.PGUP,
        KC.CAPS, KC.A, KC.S, KC.D, KC.F, KC.G, KC.H, KC.J, KC.K, KC.L, KC.SCLN, KC.QUOT, KC.ENT, KC.PGDN,
        KC.LSFT, KC.Z, KC.X, KC.C, KC.V, KC.B, KC.N, KC.M, KC.COMM, KC.DOT, KC.SLSH, KC.RSFT, KC.UP, KC.END,
        KC.LCTL, KC.LGUI, KC.LALT, KC.SPC, KC.RALT, KC.MO(1), KC.RCTL, KC.LEFT, KC.DOWN, KC.RGHT
    ],
    [
        KC.TRNS, KC.TRNS, KC.TRNS, KC.TRNS, KC.TRNS, KC.TRNS, KC.TRNS, KC.TRNS, KC.TRNS, KC.TRNS, KC.TRNS, KC.TRNS, KC.TRNS, KC.TRNS, KC.TRNS,
        KC.TRNS, KC.TRNS, KC.TRNS, KC.TRNS, KC.TRNS, KC.TRNS, KC.TRNS, KC.TRNS, KC.TRNS, KC.TRNS, KC.TRNS, KC.TRNS, KC.TRNS, KC.TRNS, KC.TRNS,
        KC.TRNS, KC.TRNS, KC.TRNS, KC.TRNS, KC.TRNS, KC.TRNS, KC.TRNS, KC.TRNS, KC.TRNS, KC.TRNS, KC.TRNS, KC.TRNS, KC.TRNS, KC.TRNS, KC.TRNS,
        KC.TRNS, KC.TRNS, KC.TRNS, KC.TRNS, KC.TRNS, KC.TRNS, KC.TRNS, KC.TRNS, KC.TRNS, KC.TRNS, KC.TRNS, KC.TRNS, KC.TRNS, KC.TRNS,
        KC.TRNS, KC.TRNS, KC.TRNS, KC.TRNS, KC.TRNS, KC.TRNS, KC.TRNS, KC.TRNS, KC.TRNS, KC.TRNS, KC.TRNS, KC.TRNS, KC.TRNS, KC.TRNS,
        KC.TRNS, KC.TRNS, KC.TRNS, KC.TRNS, KC.TRNS, KC.TRNS, KC.TRNS, KC.TRNS, KC.TRNS, KC.TRNS
    ]
]

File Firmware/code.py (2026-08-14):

import board

from kmk.kmk_keyboard import KMKKeyboard
from kmk.scanners import DiodeOrientation
from kmk.keys import KC
from kmk.modules.layers import Layers
from kmk.modules.encoder import EncoderHandler
from kmk.extensions.RGB import RGB, AnimationModes

layers = Layers()
import config


keyboard = KMKKeyboard()

keyboard.row_pins = (
    board.GP0,
    board.GP1,
    board.GP2,
    board.GP3,
    board.GP4,
    board.GP5,
)

keyboard.col_pins = (
    board.GP6,
    board.GP7,
    board.GP8,
    board.GP9,
    board.GP10,
    board.GP11,
    board.GP12,
    board.GP13,
    board.GP14,
    board.GP15,
    board.GP16,
    board.GP17,
    board.GP18,
    board.GP19,
    board.GP20,
)

keyboard.diode_orientation = DiodeOrientation.

keyboard.modules.append(layers)


# MATRIX KEYMAP

def expand_layer(compact):

    result = []

    empty = {
        3: {14},
        4: {1},
        5: {3, 4, 6, 7, 8},
    }

    index = 0

    for row in range(6):

        for col in range(15):

            if col in empty.get(row, set()):
                result.append(KC.NO)

            else:
                result.append(compact[index])
                index += 1

    return result


keyboard.keymap = [
    expand_layer(layer)
    for layer in config.KEYMAP
]


# ENCODER

encoder = EncoderHandler()

encoder.pins = (
    (board.GP21, board.GP22, None, False),
)

encoder.map = config.ENCODER_MAP

keyboard.modules.append(encoder)

# RGB

if config.LED_MODE == 0:

    print("FlexKey RGB: OFF")

else:

    animation_modes = {
        1: AnimationModes.STATIC,
        2: AnimationModes.BREATHING,
        3: AnimationModes.RAINBOW,
    }

    mode = animation_modes.get(
        config.LED_MODE,
        AnimationModes.STATIC
    )

 rgb = RGB(
        pixel_pin=board.GP28,
        num_pixels=84,
        val_limit=config.LED_VAL,
        hue_default=config.LED_HUE,
        sat_default=config.LED_SAT,
    )

    rgb.animation_mode = mode

    keyboard.extensions.append(rgb)

    print("FlexKey RGB mode:", config.LED_MODE)

oled_ext = Oled(
    OledData(
        corner_one={OledData.WPM},        # Top Left: WPM
        corner_two={OledData.LAYER},      # Top Right: Layer indicator
        corner_three={OledData.BASE},     # Bottom Left: Default text
        corner_four={OledData.BASE}       # Bottom Right
    ),
    toDisplay=OledDisplayMode.TXT,
    flip=False,
)
oled_ext._txt = config.OLED_TEXT 
keyboard.extensions.append(oled_ext)
anim_map = {
    1: AnimationModes.STATIC,
    2: AnimationModes.BREATHING,
    3: AnimationModes.RAINBOW,
    4: AnimationModes.SWIRL,
    5: AnimationModes.KNIGHT
}

selected_animation = anim_map.get(config.LED_MODE, AnimationModes.STATIC)

print("FlexKey Booting up!!!")
print("Matrix: 6 x 15")
print("Visit:")
print("https://flex-key.vercel.app")
print("for Modify with AI")
print("Flex key is ready to hack")

keyboard.go()

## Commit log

2026-07-20 Production File
    [Combin.3mf, TOP.3mf, bom.csv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]
2026-07-20 Initialize keyboard firmware with encoder and OLED support
2026-07-21 add src
    [FlexKeys.kicad_sch]
2026-07-21 ADD bom
    [bom.csv]
2026-07-21 Update README with Bill of Materials and credits
    Added a Bill of Materials section with item details, license information, contributing guidelines, and credits.
2026-07-21 Revise
    Updated the structure and content of the build guide, including new sections for ordering components and assembly steps.
2026-07-21 Revise table of contents and add assembly steps
    Updated the table of contents to reflect changes in sections and added assembly steps.
2026-08-06 added stl file
    [Combin.3mf, Combin.stl, TOP.3mf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]
2026-08-14 fixed
    keymapping and other issue
    working checked
    [code.py]
2026-08-14 final firmware Guide and Assembly
    Updated the instructions for uploading firmware and added steps for installing CircuitPython and kmk_firmware library.
2026-08-15 Revert "Relocated"
    This reverts commit 345329306242a74ccca3aad55200b929b6786446.
    [FlexKey.f3z]
2026-08-15 Revert "Relocated"
    This reverts commit 2409393114e84557696828f9c1b3c2bb99bc9873.
    [FlexKey.step]
2026-08-15 added demo
    Updated project description and added links to purchase components in the Bill of Materials section.
2026-08-15 final BOM
    [bom.csv]
2026-08-15 added final bom
    Updated PCB entry to include a link to JLCPCB.
    [bom.csv]
2026-08-15 Update build journal
    Added detailed entries for the FlexKey project development, including build completion, troubleshooting, and 3D printing updates.
2026-08-15 add pricing note
    Updated PCB price and added note about pricing.
2026-08-15 Update PCB entry with additional price information
    [bom.csv]
2026-08-15 added note
    [bom.csv]
2026-08-15 Add tip for cooling bed plates before print removal
    Added a tip about cooling bed plates before removing prints to prevent warping.
2026-08-15 Add tip
    Added a tip for self 3D printing with FDM printers regarding print removal.

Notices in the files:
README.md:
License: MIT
